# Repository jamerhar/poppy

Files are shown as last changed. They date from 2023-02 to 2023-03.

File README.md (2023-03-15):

# Poppy
### 70% Alice keyboard using THT components expanding upon [elmo's Sesame](https://github.com/kb-elmo/sesame).

### Expanding upon the Sesame, the Poppy includes a function row, solenoid support, and a resin printable case.

### Board Bill of Materials
 |Count|Part|Reference|
 |-|-|-|
 |1|ATmega32A 40 Pin DIP|U1|
 |1|40 Pin DIP Socket|U1|
 |1|USB4085-GF-A USB Type-C|J1|
 |1|500mA Polyfuse|F1|
 |2|6mm Push Button|SW1, SW2|
 |1|16MHz Quartz Crystal|X1|
 |1|4.7uF Electrolytic Capacitor|C1|
 |2|0.1uF Ceramic Disk Capacitor|C2,C3|
 |2|22pF Ceramic Disk Capacitor|C4,C5|
 |1|1.5kΩ Resistor|R1|
 |2|68Ω Resistor|R2,R3|
 |2|5.1kΩ Resistor|R4,R5|
 |1|10kΩ Resistor|R6|
 |2|3.6V Zener Diode (DO-35 BZX55C3V6)|D77,D78|
 |76|Universal Switching Diode (DO-35 1N4148)|D1-D76|
 
 This bill of materials is identical to the Sesame's minus the quantity of diodes.
 
 ### Solenoid Bill of Materials
 |Count|Part|Reference|
 |-|-|-|
 |1|Uxcell Mini Push 4.5V @ ~350mA Solenoid| |
 |1|1N4001 Diode|D1|
 |1|TIP120 Transistor|Q1|
 |1|2.2kΩ Resistor|R1|
 
 The solenoid, [purchasable on Amazon](https://www.amazon.com/gp/product/B013DR655A/ref=ppx_yo_dt_b_search_asin_title?ie=UTF8&psc=1), addon is optional and does not employ the most polished mounting and connection to the main PCB, but is functional and supported in both QMK/VIAL firmware. The easiest method is to run wires from the ATmega32A's solenoid pin (B4/pin 5) and +5V and GND from the ISP header above the 32A. Some slight changes to the PCB could be made to add a header or JST connector to the solenoid, but I haven't gotten around to it at this time.
 
 ### Case Bill of Materials
  |Count|Part|
  |-|-|
  |1|PCB|
  |1|Plate|
  |1|Bottom Case (3D/Resin Printed)|
  |1|Top Case (3D/Resin Printed)|
  |1|Weight|
  |4|10mm Diameter Adhesive Bumpons|
  |19|Brass Screw-to-Expand Inserts, M2x4mm|
  |19|M2x5mm Button Head Screw|
  |1|Solenoid Daugherboard PCB (Optional)|
  |1|Solenoid Driver PCB (Optional)|
  |2|M2x3mm Socket/Button Head Screw (Optional)|
  
  8 M2x5mm screws and screw-to-expend inserts, [purchasable on McMaster](https://www.mcmaster.com/94510A611/), are used to secure both halves of the case. 4 M2x5mm screws and inserts are used to secure the plate to the top case. 5 M2x5mm screws and inserts are used to secure the optional solenoid/driver board to the bottom case. 2 M2x3mm screws are used to secure the solenoid to the solenoid daughterboard. 2 M2x5mm screws are used to secure the weight to the bottom case, countersunk holes can be drilled and flat head screws can be used for a flush look. I had my case printed through JLCPCB's resin 3D printing services since I don't have a printer large enough for this board. I've had successful prints with both 8000 resin and 8111X resin, with the latter being cheaper. There is a small amount of warping throughout the thin F-row separating area on both of my prints due to the extremely thin geometry, but it does not interfere during use (YMMV). 
  
### Disclaimer
I do not offer any sort of warranty, nor can I be held liable if something goes wrong.
Please thoroughly review the design, especially involving the case, before ordering anything. There are possibly small errors and other defects within the design, this was my first attempt at case design and it is by no means perfect.

### Additional Images
One revision out of date bottom case:


Weight and solenoid driver wiring:


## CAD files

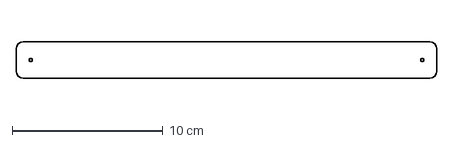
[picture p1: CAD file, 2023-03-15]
Case/poppy_weight v1.dxf
27.9 x 2.40 cm

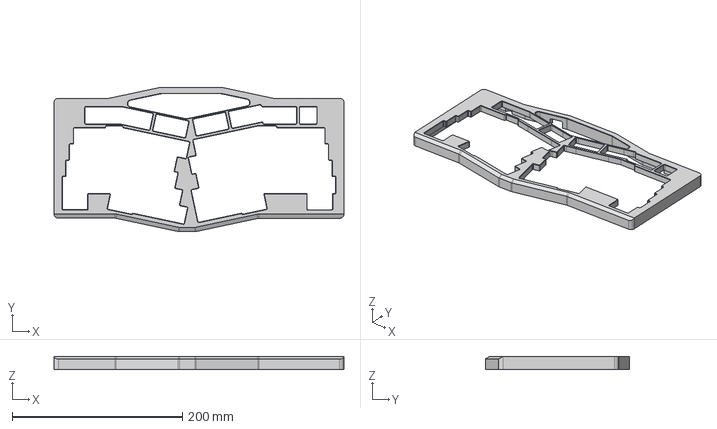
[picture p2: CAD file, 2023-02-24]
Case/poppy_finaltopcase v2.step
340.6 x 169.6 x 15.3 mm

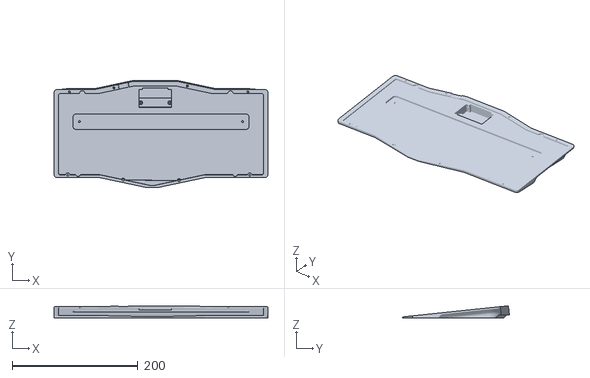
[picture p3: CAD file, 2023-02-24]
Case/poppy_bottomcasesol.stl
340.6 x 170.2 x 19.9

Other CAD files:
Case/poppy_bottomcasefinalledgev2 v12.step
Case/poppy_finalbottomcasev2.stl
Case/poppy_finaltopcase.stl

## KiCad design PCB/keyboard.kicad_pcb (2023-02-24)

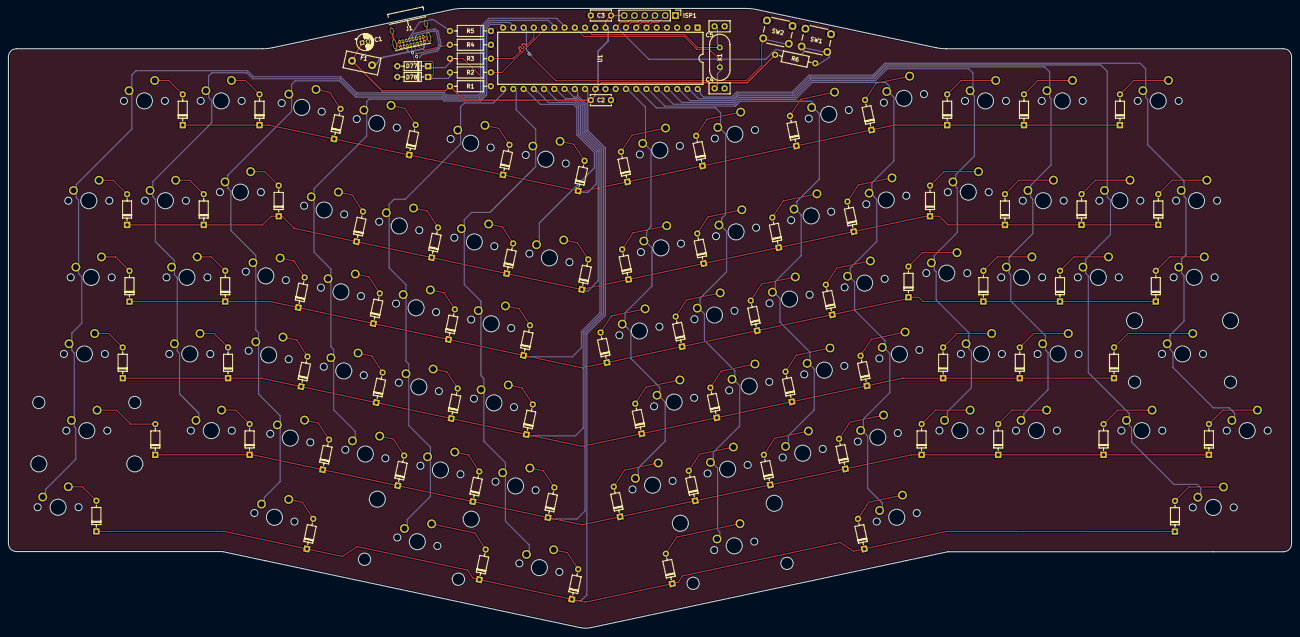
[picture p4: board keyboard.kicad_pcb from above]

Board: 2 copper layers, 318.4 x 153.8 mm, 172 parts (0 on the bottom side), 113 nets.

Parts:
C1: 4.7u; CP_Radial_D4.0mm_P1.50mm
C2, C3: 0.1u; C_Disc_D5.0mm_W2.5mm_P5.00mm
C4, C5: 22p; C_Disc_D5.0mm_W2.5mm_P2.50mm
D1: F1; D_DO-35_SOD27_P7.62mm_Horizontal
D2: F2; D_DO-35_SOD27_P7.62mm_Horizontal
D3: F3; D_DO-35_SOD27_P7.62mm_Horizontal
D4: F4; D_DO-35_SOD27_P7.62mm_Horizontal
D5: F5; D_DO-35_SOD27_P7.62mm_Horizontal
D6: F6; D_DO-35_SOD27_P7.62mm_Horizontal
D7: F7; D_DO-35_SOD27_P7.62mm_Horizontal
D8: F8; D_DO-35_SOD27_P7.62mm_Horizontal
D9: F9; D_DO-35_SOD27_P7.62mm_Horizontal
D10: F10; D_DO-35_SOD27_P7.62mm_Horizontal
D11: F11; D_DO-35_SOD27_P7.62mm_Horizontal
D12: F12; D_DO-35_SOD27_P7.62mm_Horizontal
D13: F13; D_DO-35_SOD27_P7.62mm_Horizontal
D14: ESC; D_DO-35_SOD27_P7.62mm_Horizontal
D15: 1; D_DO-35_SOD27_P7.62mm_Horizontal
D16: 2; D_DO-35_SOD27_P7.62mm_Horizontal
D17: 3; D_DO-35_SOD27_P7.62mm_Horizontal
D18: 4; D_DO-35_SOD27_P7.62mm_Horizontal
D19: 5; D_DO-35_SOD27_P7.62mm_Horizontal
D20: 6; D_DO-35_SOD27_P7.62mm_Horizontal
D21: 7; D_DO-35_SOD27_P7.62mm_Horizontal
D22: 8; D_DO-35_SOD27_P7.62mm_Horizontal
D23: 9; D_DO-35_SOD27_P7.62mm_Horizontal
D24: 0; D_DO-35_SOD27_P7.62mm_Horizontal
D25: MINS; D_DO-35_SOD27_P7.62mm_Horizontal
D26: EQL; D_DO-35_SOD27_P7.62mm_Horizontal
D27: BSLS; D_DO-35_SOD27_P7.62mm_Horizontal
D28: DEL; D_DO-35_SOD27_P7.62mm_Horizontal
D29: TAB; D_DO-35_SOD27_P7.62mm_Horizontal
D30: Q; D_DO-35_SOD27_P7.62mm_Horizontal
D31: W; D_DO-35_SOD27_P7.62mm_Horizontal
D32: E; D_DO-35_SOD27_P7.62mm_Horizontal
D33: R; D_DO-35_SOD27_P7.62mm_Horizontal
D34: T; D_DO-35_SOD27_P7.62mm_Horizontal
D35: Y; D_DO-35_SOD27_P7.62mm_Horizontal
D36: U; D_DO-35_SOD27_P7.62mm_Horizontal
D37: I; D_DO-35_SOD27_P7.62mm_Horizontal
D38: O; D_DO-35_SOD27_P7.62mm_Horizontal
D39: P; D_DO-35_SOD27_P7.62mm_Horizontal
D40: LBRC; D_DO-35_SOD27_P7.62mm_Horizontal
D41: RBRC; D_DO-35_SOD27_P7.62mm_Horizontal
D42: BSPC; D_DO-35_SOD27_P7.62mm_Horizontal
D43: CAPS; D_DO-35_SOD27_P7.62mm_Horizontal
D44: A; D_DO-35_SOD27_P7.62mm_Horizontal
D45: S; D_DO-35_SOD27_P7.62mm_Horizontal
D46: D; D_DO-35_SOD27_P7.62mm_Horizontal
D47: F; D_DO-35_SOD27_P7.62mm_Horizontal
D48: G; D_DO-35_SOD27_P7.62mm_Horizontal
D49: H; D_DO-35_SOD27_P7.62mm_Horizontal
D50: J; D_DO-35_SOD27_P7.62mm_Horizontal
D51: K; D_DO-35_SOD27_P7.62mm_Horizontal
D52: L; D_DO-35_SOD27_P7.62mm_Horizontal
D53: SCLN; D_DO-35_SOD27_P7.62mm_Horizontal
D54: QUOT; D_DO-35_SOD27_P7.62mm_Horizontal
D55: ENT; D_DO-35_SOD27_P7.62mm_Horizontal
D56: LSFT; D_DO-35_SOD27_P7.62mm_Horizontal
D57: Z; D_DO-35_SOD27_P7.62mm_Horizontal
D58: X; D_DO-35_SOD27_P7.62mm_Horizontal
D59: C; D_DO-35_SOD27_P7.62mm_Horizontal
D60: V; D_DO-35_SOD27_P7.62mm_Horizontal
D61, D62: B; D_DO-35_SOD27_P7.62mm_Horizontal
D63: N; D_DO-35_SOD27_P7.62mm_Horizontal
D64: M; D_DO-35_SOD27_P7.62mm_Horizontal
D65: COMM; D_DO-35_SOD27_P7.62mm_Horizontal
D66: DOT; D_DO-35_SOD27_P7.62mm_Horizontal
D67: SLSH; D_DO-35_SOD27_P7.62mm_Horizontal
D68: RSFT; D_DO-35_SOD27_P7.62mm_Horizontal
D69: FN2; D_DO-35_SOD27_P7.62mm_Horizontal
D70: LCTL; D_DO-35_SOD27_P7.62mm_Horizontal
D71: LALT; D_DO-35_SOD27_P7.62mm_Horizontal
D72: SPC; D_DO-35_SOD27_P7.62mm_Horizontal
D73: LGUI; D_DO-35_SOD27_P7.62mm_Horizontal
D74: FN1; D_DO-35_SOD27_P7.62mm_Horizontal
D75: RALT; D_DO-35_SOD27_P7.62mm_Horizontal
D76: RCTL; D_DO-35_SOD27_P7.62mm_Horizontal
D77, D78: 3.6V; D_DO-35_SOD27_P7.62mm_Horizontal
F1: 500mA; Fuse_Littelfuse_395Series
ISP1: Conn_01x06; PinHeader_1x06_P2.54mm_Vertical
J1: USB_C_Receptacle_USB2.0; USB_C_GCT_USB4085
MX1, MX2, MX3, MX4, MX5, MX6, MX7, MX8, MX9, MX10, MX11, MX12, MX13, MX14, MX15, MX16, MX17, MX18, MX19, MX20, MX21, MX22, MX23, MX24, MX25, MX26, MX27, MX28, MX30, MX31, MX32, MX33, MX34, MX35, MX36, MX37, MX38, MX39, MX40, MX41, MX44, MX45, MX46, MX47, MX48, MX49, MX50, MX51, MX52, MX53, MX54, MX57, MX58, MX59, MX60, MX61, MX62, MX63, MX64, MX65, MX66, MX67, MX69, MX73: KEYSW; MXOnly-1U-NoLED
MX29, MX42, MX70, MX71, MX75, MX76: KEYSW; MXOnly-1.5U-NoLED
MX43, MX68: KEYSW; MXOnly-1.75U-NoLED
MX55, MX72: KEYSW; MXOnly-2.25U-ReversedStabilizers-NoLED
MX56: KEYSW; MXOnly-2.25U-NoLED
MX74: KEYSW; MXOnly-2.75U-ReversedStabilizers-NoLED
R1: 1.5K; R_Axial_DIN0207_L6.3mm_D2.5mm_P10.16mm_Horizontal
R2, R3: 68; R_Axial_DIN0207_L6.3mm_D2.5mm_P10.16mm_Horizontal
R4, R5: 5.1K; R_Axial_DIN0207_L6.3mm_D2.5mm_P10.16mm_Horizontal
R6: 10K; R_Axial_DIN0207_L6.3mm_D2.5mm_P10.16mm_Horizontal
SW1: RESET; SW_PUSH_6mm
SW2: BOOT; SW_PUSH_6mm
U1: ATmega32A-PU; DIP-40_W15.24mm
X1: Crystal; Crystal_HC49-4H_Vertical

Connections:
+5V: C1.1, C2.1, C3.1, F1.1, ISP1.6, R1.2, R6.1, U1.10, U1.30
BOOT: SW2.2, U1.18
D+: R2.1, U1.16
D-: R3.1, U1.17
GND: C1.2, C2.2, C3.2, C4.2, C5.2, D77.2, D78.2, ISP1.1, J1.A1, J1.A12, J1.B1, J1.B12, J1.S1, R4.1, R5.1, SW1.1, SW2.1, U1.11, U1.31
MISO: ISP1.3, U1.7
MOSI: ISP1.2, U1.6
unnamed: C4.1, U1.13, X1.2
unnamed: C5.1, U1.12, X1.1
unnamed: D1.2, MX1.2
unnamed: D2.2, MX2.2
unnamed: D3.2, MX3.2
unnamed: D4.2, MX4.2
unnamed: D5.2, MX5.2
unnamed: D6.2, MX6.2
unnamed: D7.2, MX7.2
unnamed: D8.2, MX8.2
unnamed: D9.2, MX9.2
unnamed: D10.2, MX10.2
unnamed: D11.2, MX11.2
unnamed: D12.2, MX12.2
unnamed: D13.2, MX13.2
unnamed: D14.2, MX14.2
unnamed: D15.2, MX15.2
unnamed: D16.2, MX16.2
unnamed: D17.2, MX17.2
unnamed: D18.2, MX18.2
unnamed: D19.2, MX19.2
unnamed: D20.2, MX20.2
unnamed: D21.2, MX21.2
unnamed: D22.2, MX22.2
unnamed: D23.2, MX23.2
unnamed: D24.2, MX24.2
unnamed: D25.2, MX25.2
unnamed: D26.2, MX26.2
unnamed: D27.2, MX27.2
unnamed: D28.2, MX28.2
unnamed: D29.2, MX29.2
unnamed: D30.2, MX30.2
unnamed: D31.2, MX31.2
unnamed: D32.2, MX32.2
unnamed: D33.2, MX33.2
unnamed: D34.2, MX34.2
unnamed: D35.2, MX35.2
unnamed: D36.2, MX36.2
unnamed: D37.2, MX37.2
unnamed: D38.2, MX38.2
unnamed: D39.2, MX39.2
unnamed: D40.2, MX40.2
unnamed: D41.2, MX41.2
unnamed: D42.2, MX42.2
unnamed: D43.2, MX43.2
unnamed: D44.2, MX44.2
unnamed: D45.2, MX45.2
unnamed: D46.2, MX46.2
unnamed: D47.2, MX47.2
unnamed: D48.2, MX48.2
unnamed: D49.2, MX49.2
unnamed: D50.2, MX50.2
unnamed: D51.2, MX51.2
unnamed: D52.2, MX52.2
unnamed: D53.2, MX53.2
unnamed: D54.2, MX54.2
unnamed: D55.2, MX55.2
unnamed: D56.2, MX56.2
unnamed: D57.2, MX57.2
unnamed: D58.2, MX58.2
unnamed: D59.2, MX59.2
unnamed: D60.2, MX60.2
unnamed: D61.2, MX61.2
unnamed: D62.2, MX62.2
unnamed: D63.2, MX63.2
unnamed: D64.2, MX64.2
unnamed: D65.2, MX65.2
unnamed: D66.2, MX66.2
unnamed: D67.2, MX67.2
unnamed: D68.2, MX68.2
unnamed: D69.2, MX69.2
unnamed: D70.2, MX70.2
unnamed: D71.2, MX71.2
unnamed: D72.2, MX72.2
unnamed: D73.2, MX73.2
unnamed: D74.2, MX74.2
unnamed: D75.2, MX75.2
unnamed: D76.2, MX76.2
unnamed: D77.1, J1.A7, J1.B7, R1.1, R3.2
unnamed: D78.1, J1.A6, J1.B6, R2.2
unnamed: J1.A5, R4.2
unnamed: J1.B5, R5.2
RESET: ISP1.5, R6.2, SW1.2, U1.9
SCK: ISP1.4, U1.8
VCC: F1.2, J1.A4, J1.A9, J1.B4, J1.B9
col0: MX1.1, MX14.1, MX29.1, MX43.1, MX56.1, MX70.1, U1.14
col1: MX2.1, MX15.1, MX30.1, MX44.1, MX57.1, U1.15
col2: MX3.1, MX16.1, MX31.1, MX45.1, MX58.1, MX71.1, U1.19
col3: MX4.1, MX17.1, MX32.1, MX46.1, MX59.1, U1.20
col4: MX5.1, MX18.1, MX33.1, MX47.1, MX60.1, MX72.1, U1.21
col5: MX6.1, MX19.1, MX34.1, MX48.1, MX61.1, MX73.1, U1.22
col6: MX20.1, U1.23
col7: MX7.1, MX21.1, MX35.1, MX49.1, MX62.1, U1.33
col8: MX8.1, MX22.1, MX36.1, MX50.1, MX63.1, MX74.1, U1.34
col9: MX9.1, MX23.1, MX37.1, MX51.1, MX64.1, U1.35
col10: MX10.1, MX24.1, MX38.1, MX52.1, MX65.1, MX75.1, U1.36
col11: MX11.1, MX25.1, MX39.1, MX53.1, MX66.1, U1.37
col12: MX12.1, MX26.1, MX40.1, MX54.1, MX67.1, U1.38
col13: MX27.1, MX41.1, MX68.1, MX76.1, U1.39
col14: MX13.1, MX28.1, MX42.1, MX55.1, MX69.1, U1.40
row0: D1.1, D2.1, D3.1, D4.1, D5.1, D6.1, D7.1, D8.1, D9.1, D10.1, D11.1, D12.1, D13.1, U1.24
row1: D14.1, D15.1, D16.1, D17.1, D18.1, D19.1, D20.1, D21.1, D22.1, D23.1, D24.1, D25.1, D26.1, D27.1, D28.1, U1.25
row2: D29.1, D30.1, D31.1, D32.1, D33.1, D34.1, D35.1, D36.1, D37.1, D38.1, D39.1, D40.1, D41.1, D42.1, U1.26
row3: D43.1, D44.1, D45.1, D46.1, D47.1, D48.1, D49.1, D50.1, D51.1, D52.1, D53.1, D54.1, D55.1, U1.27
row4: D56.1, D57.1, D58.1, D59.1, D60.1, D61.1, D62.1, D63.1, D64.1, D65.1, D66.1, D67.1, D68.1, D69.1, U1.28
row5: D70.1, D71.1, D72.1, D73.1, D74.1, D75.1, D76.1, U1.29
